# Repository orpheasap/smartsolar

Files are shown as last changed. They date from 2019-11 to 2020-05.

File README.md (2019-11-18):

# smartsolar – Μια συσκευή για την καλύτερη διαχείριση του ηλιακού θερμοσίφωνα

Θα ασχοληθούμε με την αυτοματοποίηση του ηλιακού θερμοσίφωνα του σπιτιού μας, με σκοπό την μεγιστοποίηση της χρήσης του ζεστού νερού που παράγεται από αυτόν. 

Ο ηλιακός θερμοσίφωνας υπάρχει στα περισσότερα σπίτια στην Ελλάδα. Κάτι που λείπει όμως στις περισσότερες εγκαταστάσεις ηλιακών είναι μια ένδειξη για το αν έχουν ζεστό νερό. Αυτό έχει σαν αποτέλεσμα πολύ συχνά, ιδίως το χειμώνα, να ανάβουμε άσκοπα τον ηλεκτρικό θερμοσίφωνα επειδή δεν είμαστε σίγουροι αν υπάρχει αρκετό ζεστό νερό στον ηλιακό. Έτσι σπαταλάται πολύ ενέργεια. 

Η λύση που σκεφτήκαμε είναι να τοποθετήσουμε ένα θερμόμετρο που θα μετράει τη θερμοκρασία του νερού μέσα στον ηλιακό θερμοσίφωνα. Το θερμόμετρο θα συνδέεται με μια πλακέτα Raspberry Pi, η οποία θα καταγράφει τις τιμές και θα μπορεί να δείξει την τρέχουσα θερμοκρασία, την τάση αύξησης ή πτώσης καθώς και διαγράμματα προηγούμενων ημερών. Το Raspberry Pi θα είναι εξοπλισμένο με wifi και συνεπώς θα υπάρχει πρόσβαση σε αυτές τις πληροφορίες μέσω δικτύου. Θα κατασκευαστεί μια εφαρμογή για android (με AppInventor) που θα συνδέεται με το Raspberry Pi και θα παρουσιάζει όλες τις πληροφορίες στο χρήστη. Το Raspberry Pi και τα άλλα ηλεκτρονικά εξαρτήματα θα τοποθετηθούν σε ένα ειδικό κουτί, το οποίο θα σχεδιάσουμε σε CAD software και θα κατασκευάσουμε με 3D printer.

## Υλικά που θα χρησιμοποιήσουμε:
- Raspberry Pi Zero Wireless (16 €)
- Αισθητήρας θερμοκρασίας DS18B20 (2 €)
- Καλώδια, αντιστάσεις κλπ (~ 5  €)
- Power Supply 5V 2.5A - Raspberry Pi (10 €)

**Συνολικό κόστος: ~33 €**

## Εργαλεία και λογισμικό
- Βασικά εργαλεία (κατσαβίδι,πένσα,κόφτη…)
- Θερμικό κολλητήρι
- 3D Printer, Creality Ender 3 Pro, Open Source Hardware
- FreeCAD, Λογισμικό CAD Ανοιχτού Κώδικα
- AppInventor, Περιβάλλον προγραμματισμού εφαρμογών Android, Ανοιχτού Κώδικα
- Fritzing, Λογισμικό ανοιχτού κώδικα σχεδίασης ηλεκτρονικών κυκλωμάτων

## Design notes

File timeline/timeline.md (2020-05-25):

# smartsolar timeline

## 27/12/2019
We bought the following: 
- Temperature Sensor - Waterproof (DS18B20)
- Jumper Wires 15cm Female to Male - Pack of 10 Red
- Breadboard Mini - White
- Resistor Basic Kit - 100pcs

## 28/12/2019
- We conected the DS18B20 to the raspberry pi, following the instractions on http://www.circuitbasics.com/raspberry-pi-ds18b20-temperature-sensor-tutorial/. 
- Then we wrote a C program, based on https://www.raspberrypi.org/forums/viewtopic.php?t=70709, to read the sensor readings. 
- We made some changes to the C program so that it converts the readings of the sensor, which are in character mode, into actual numbers. The source code can be seen [here](../timeline/code/temp.c)
- This is a screenshot of the program output while running:
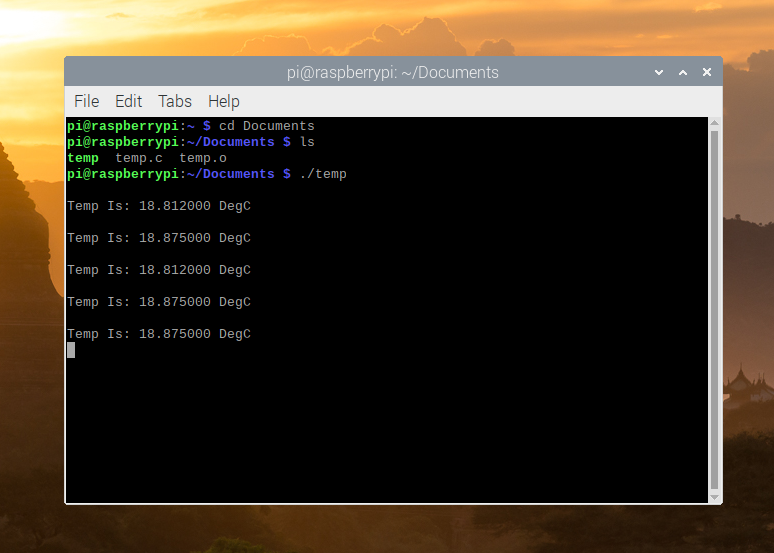
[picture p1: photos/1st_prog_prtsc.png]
PrtSc taken on the raspberry pi


## 6/1/2020
- To send the sensor's readings from the raspberry pi to another device we are using the [mqtt protocol](https://mqtt.org), wich is a protocol that makes communication between devices through network easier.
- We installed the following mqtt implementations for raspberry pi:
  - the mosquito broker, by typing in the terminal: `sudo apt install mosquitto`.
  - and the mosquito clients, by typing in the terminal: `sudo apt-get install mosquitto-clients`.
- Then we wrote a C program which publishes the sensor's readings to the broker. The source code can be seen [here](../timeline/code/temp_mqtt.c).
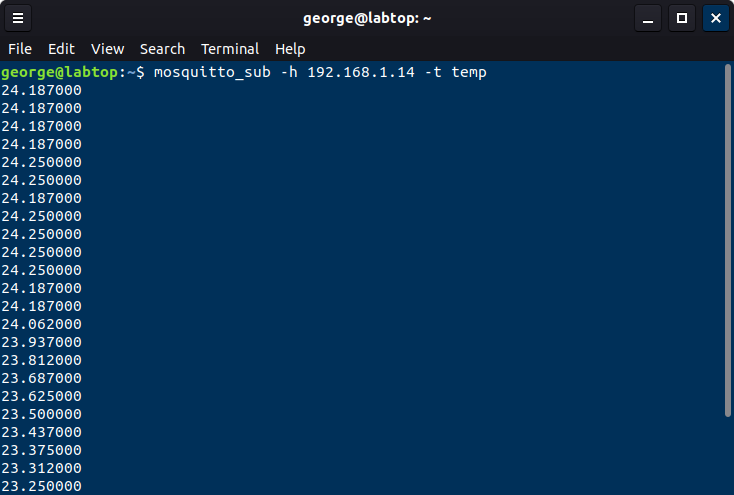
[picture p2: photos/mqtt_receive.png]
PrtSc taken on an other computer
- Now the raspberry pi can send the sensor's readings to other devices through network. Here is a screenshot of an other computer, in wich we have installed the mosquitto clients, receiving the sensor's readings: 

The command `mosquitto_sub -h 192.168.1.14 -t temp` subscribes to the raspberry pi (ip = 192.168.1.14) and reads the the temperature from the mqtt topic "temp".

## 2/2/2020
- We installed the sensor in the solar heater using some silicon to secure it in place. The sensor was placed inside of a thermowell as you can see in the following picture: photo taken while istalling the sensor
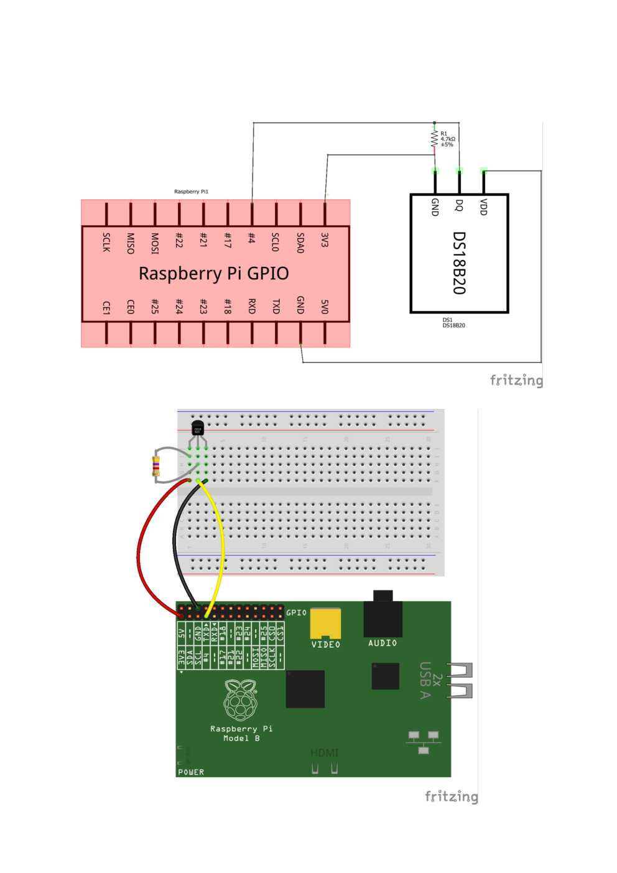
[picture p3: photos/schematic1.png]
the shcematic was created in fritzing
- Then we used a long, 3-wire cable to conect the sensor, in the heater, to the rasberry pi wich is located in a room one floor benith the solar heater. In order to conect the wire to the rasbperry pi easier we created a bracket. In the following pictures you can see the schematic and photos of the bracket: 
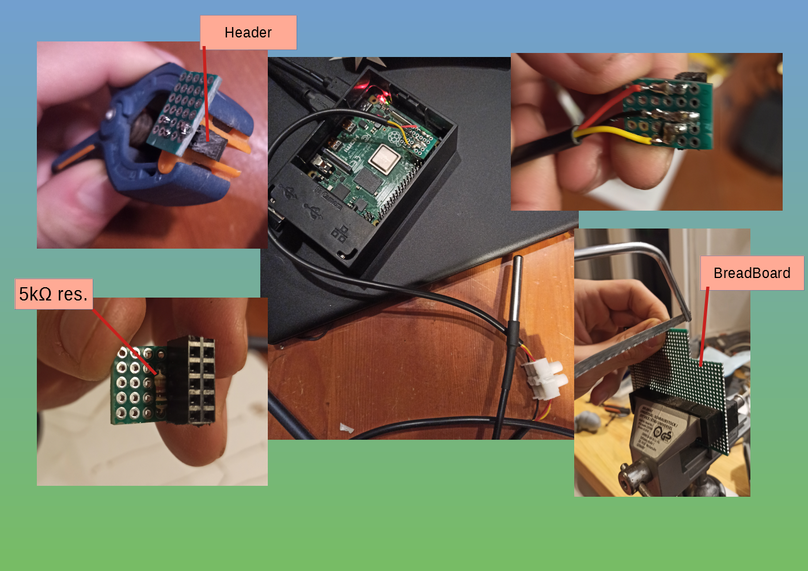
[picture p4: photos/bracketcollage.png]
photos taken during the building process of the bracket


## 9/2/2020
- We extended the C program temp_mqtt.c, which makes a string that contains temperature readings from the past 3 hours. Every 15 minutes the program places a new reading in the string, deleting 12th one, and publishes the string on the mqtt briker to the topic `-t temp_chart`. So the string contains 12 readings(starting with the latest one). The source code can be found [here](../timeline/code/temp_mqtt_chart.c).
- We also made the pi to run the program at startup, following the instructions for the first method(rc.local) illustrated on this website:https://www.dexterindustries.com/howto/run-a-program-on-your-raspberry-pi-at-startup/. When editing rc.local, in order to run the executable program temp_mqtt(wich is the executable program of the temp_mqtt_chart.c) at startup, we added the line `sudo home/pi/Documents/temp_mqtt &` before the line `exit 0`. 

## 10/2/2020
The main focus of the project is to create an aplication where we can wacth the temprature of the solarheater and a diagram of some previous readings. The app will be created on the [appinventor platform](http://appinventor.mit.edu/). In order to connect the app inventor platform with the mqtt broker, we are using the capability of appinventor to run javascript via an html website[html website](https://el.wikipedia.org/wiki/HTML). To achieve a connection between javascript and mqtt, we have to use websockets. The mosquitto broker is not regulary running with websockets enabled, so we have to activate them.
- In order to activate the websockets, we edited the mosquitto configuration file mosquitto.conf using the comand `sudo nano /etc/mosquitto/mosquitto.conf` and aded the two following lines: `listener 9001` and `protocol websockets`. Some information on how to activate websockets we found on the site: https://www.sitepoint.com/community/t/basic-javascript-example-using-mosquitto-mqtt/308792.
- Our 1st html file, is based on the one, illustreated on this website: https://internetofhomethings.com/homethings/?p=1317. The source code for our html file can be found here [here](../timeline/code/smartsolar1.html). It subscribes to the mqtt topic `-t temp` and reads the messages published on the topic. 
- Our 2nd html file, is almost identical to the first one. The only difference is that it subscribes to the mqtt topic `-t temp_chart`, and reads the messege, wich is a string containing 12 readings with one space between them. The source code can be found [here](../timeline/code/smartsolar2.html). 

## 15/2/2020
The app, must be able to run both html files. To achieve that we incleded two screens, wich can be swhitched between with one button at the top of the screen. Each screen cheks if there has been a new messege published in the mqtt topic, every number of seconds. 
- The first screen connects to the first html file, and posts the new reading on a label.
- The second screen connects to the second html file. When it recieves the new reading(every 15min.) it splits it at spaces and creates an array of 12 strings. The 12th string of the array contains the latest reading, the 11th contains the reading wich was taken 15 minutes befor the latest one, and so on... Then it creates a diagram with 11 lines. Each line's ends represent a sensor reading.
   - The horizontlal axis is devided in 12 poits. At the zero of the axis, there is the reading taken 3 hours before the latest one and on the end of the axis there is the latest reading.
   - The vertical axis is devided in 100 points. Each point represents a number of °C(ranging from 0-100).
- Below can see a screenshot off the second screen of the app, running on a phone:
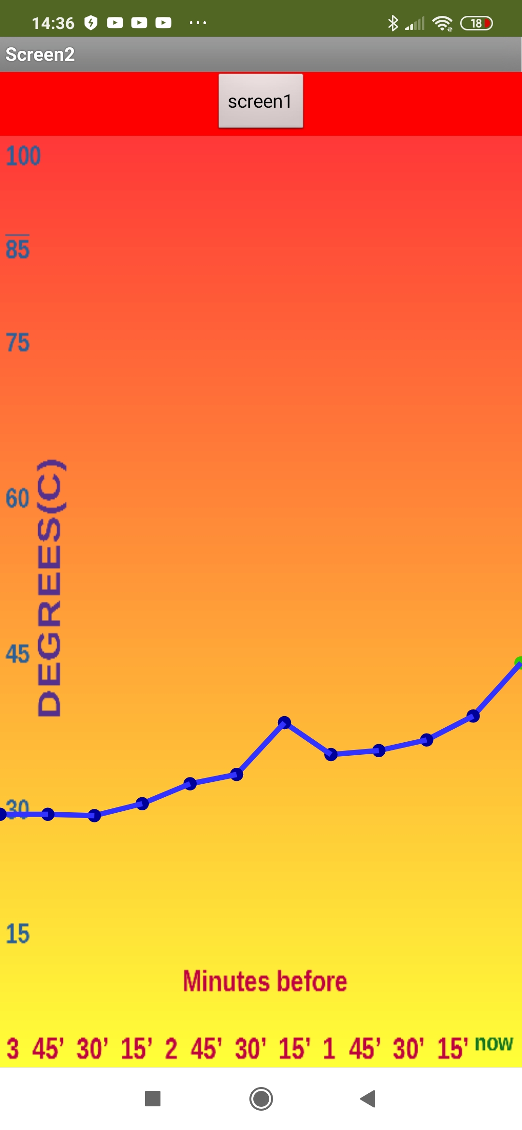
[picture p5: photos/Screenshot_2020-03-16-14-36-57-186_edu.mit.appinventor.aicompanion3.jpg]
Screenshot taken on phone


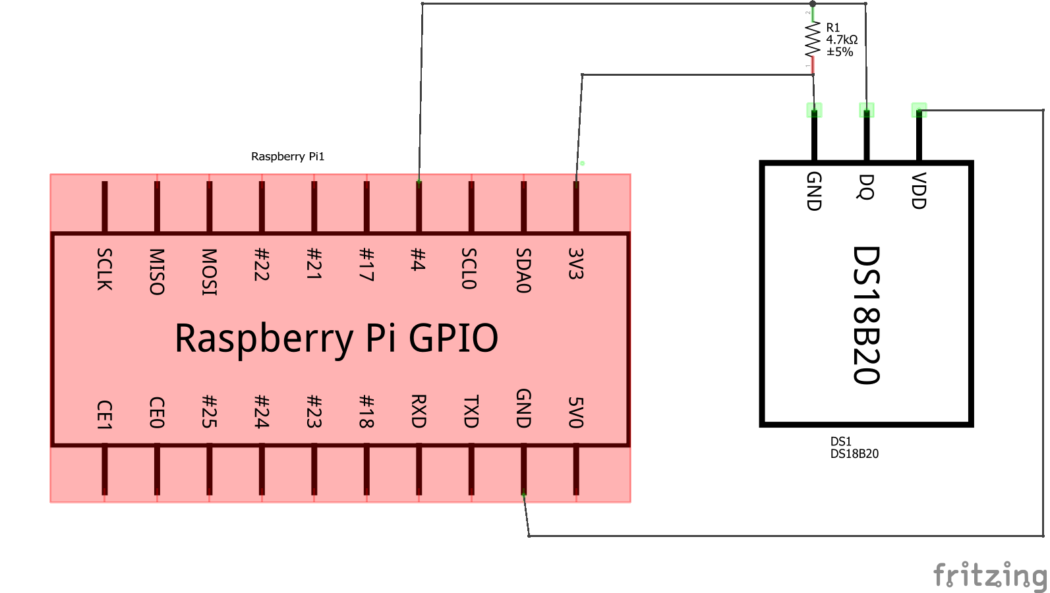
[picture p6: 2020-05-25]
cad/schematic1_schem.png

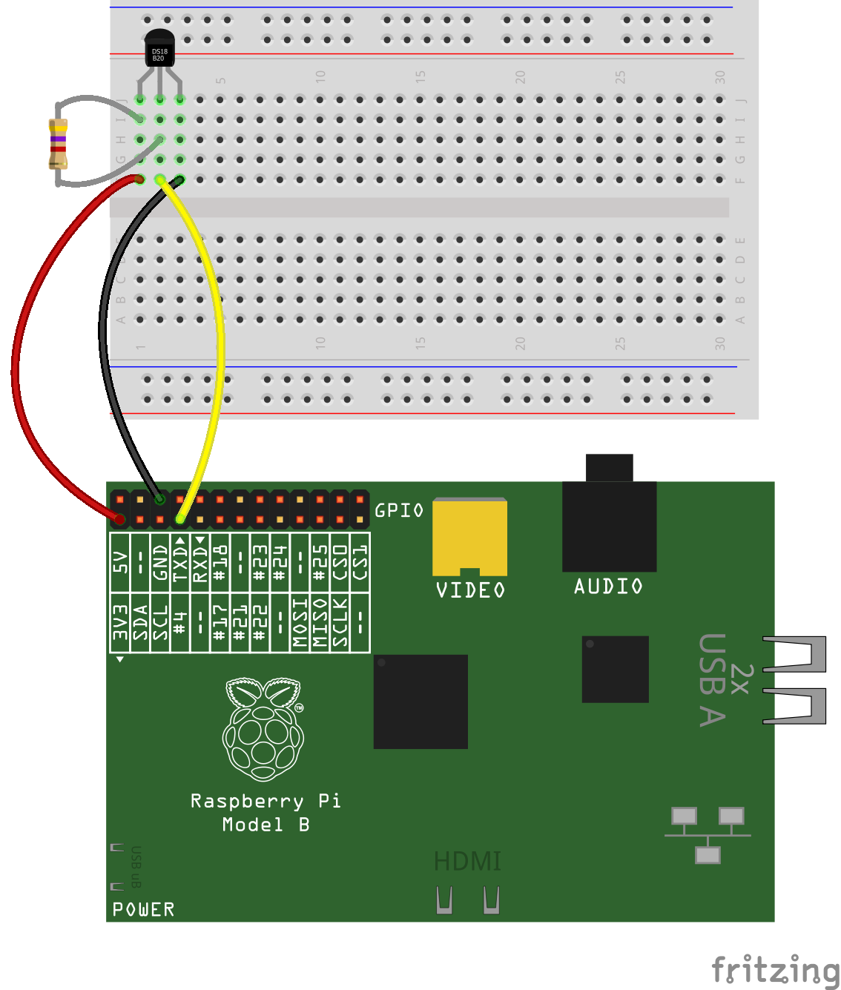
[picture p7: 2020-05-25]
cad/schematic1_bb.png

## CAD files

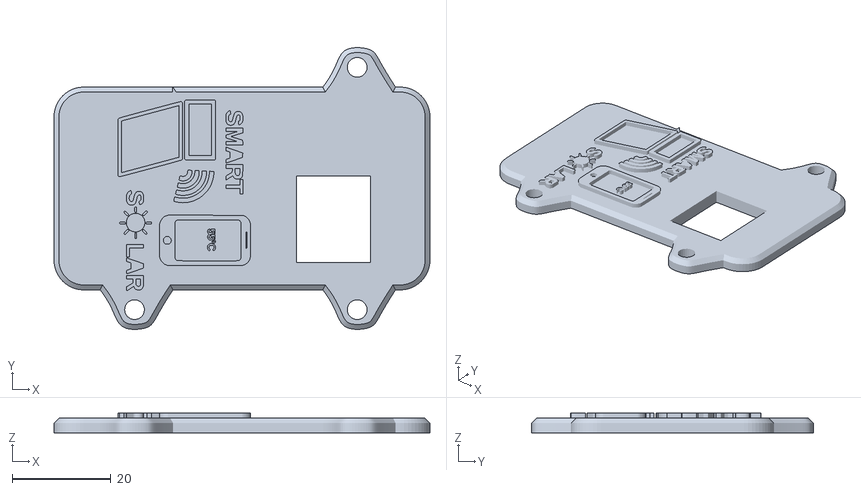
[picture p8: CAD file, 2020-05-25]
cad/cap.stl
76.0 x 57.0 x 4.00

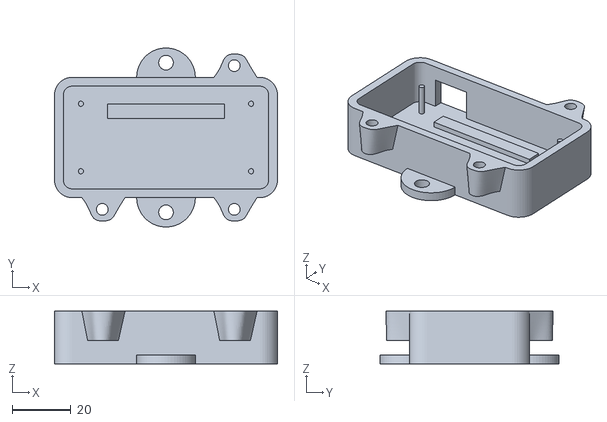
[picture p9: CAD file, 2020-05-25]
cad/body.stl
76.0 x 61.0 x 18.0
